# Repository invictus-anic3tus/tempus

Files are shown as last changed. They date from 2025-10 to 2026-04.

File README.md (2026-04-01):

<div align="center" width=100%>

  Tempus Title Image

  Tempus Title Image

  <p display="inline">

  

  </p>

  <h1></h1>

  <p>
    An open source, ESP32-based smartwatch!
  </p>
</div>

<sub>This work is licensed under a
[Creative Commons Attribution-NonCommercial 4.0 International License](https://creativecommons.org/licenses/by-nc/4.0/).
</sub>

## Table of Contents

- [About](#about)
- [Features](#features)
- [Specifications](#specifications)
- [Bill of Materials](#bill-of-materials)
- [Contributing](#contributing)

## About

My name is Anicetus, and I love hardware. The Anicept Tempus is my newest addition to my brand, and the first devboard PCB! There are others out there, and many are probably much better. But I felt it was high time I had one of my _own._ It might not beat the competition in price, features, quality, you name it; but there comes a certain satisfaction when you can wear (more like tout at this point) a semi-stylish, functional, and helpful item that you can point to and confidently say: "I created this from scratch."

And so, the Tempus is a small yet powerful ESP32 devboard PCB + case, equipped with all the features that a modern digital smartwatch would need. Fully able to track steps and gestures, voice text, make beeps and alerts with a buzzer, power a round touchscreen, and, of course, tell time, it's the ideal replacement for a multi-hundred-dollar smartwatch with the same features.

## Features

Speaking of features, this watch is equipped with the following:
- A precise, quick gyroscope/accelerometer for hand tracking
- WiFi and Bluetooth for connecting to your phone to receive texts and calls, as well as control music apps such as Spotify
- An RTC (Real Time Clock) chip capable of maintaining incredibly accurate time
- A vibration motor for alerts and ringtones
- A microphone for voice messaging or reminders. (Note: the watch doesn't have a speaker, so playing music, receiving calls, etc. must be done through headphones connected to a phone connected to the watch. Also, unfortunately the ESP32-S3 cannot be used as a microphone during calls, so for that you'll need to use your phone's built-in mic.)
- Two reprogrammable buttons, perfect for quick text replies, controlling music, or navigating to apps.
- A modern USB-C 2.0 charging and programming recepticle
- A 500mAh battery, to ensure minimal charging time
- A battery percentage monitor to ensure the watch never dies
- A 1.28" capacitive touch display

## How do I build this?

Good question! If you'd like to make the Tempus for yourself, there's a few things you should keep in mind:
1. You must have access to a 3D printer or be willing to pay for a printing service. TPU or another flexible filament is required for the watch band.
2. You must have access to soldering equipment and be skilled in soldering. This includes a hot air gun and solder paste.
3. This design necessitates a custom PCB. These can get expensive if you need to account for shipping or tariff costs.
4. This is _not_ a professional design! I'm a random guy from the internet who made a smartwatch design; if you want to make it for yourself, go ahead! But I am not responsible for any misuse or unintended happenings due to faulty design.
5. Commercial use is not allowed. You cannot make this watch to sell to anybody.

Alright! Now we can get into how to actually build it. First, download the gerber.zip file in the PCB_Production folder, go to your favorite PCB manufacturing service (JLCPCB and PCBWay are good) and upload it in their quote system. It should say four-layer PCB. Here are the settings to select:
(Make sure you know what you're doing before changing these! The color is self-explanatory, but colors other than green can be more expensive.)

JLCPCB settings

Then, order the DigiKey parts in [this cart](https://www.digikey.com/short/2mbbn5n0) and the screen from [BuyDisplay](https://www.buydisplay.com/1-28-inch-tft-lcd-display-240x240-round-circle-screen-for-smart-watch) or [eBay](https://www.ebay.com/itm/305668452899?var=604666595108).

Next, 3D print the files in the CAD folder. Detailed assembly instructions coming soon; for now, please reference the full CAD design!

Wiring

## Specifications

Nerd info incoming
- Main processor: ESP32-S3-Wroom-1
- Gyroscope/accelerometer: LSM6DSMTR
- RTC: DS3231M+
- Battery Charging: TPB4056B (A drop-in TP4056 replacement, available on DigiKey)
- Microphone: SPH0645LM4H-B
- Display: [1.28 inch 240x240 IPS TFT LCD Round Circle Capacitive Touch Screen](https://www.buydisplay.com/1-28-inch-tft-lcd-display-240x240-round-circle-screen-for-smart-watch)
- Main 3v3 Buck-Boost Converter: TPS63031DSKR

Tempus Schematic-1

PCB

## Bill of Materials

| Item |  Price  | Link | Shipping |
|---|---|---|---|
| PCB | $2 | <https://jlcpcb.com> | $3.18 |
| DigiKey Parts* | $67.34  | <https://www.digikey.com/short/2mbbn5n0> | $6.99 |
| Screen | $8.85 | <https://www.buydisplay.com/1-28-inch-tft-lcd-display-240x240-round-circle-screen-for-smart-watch> | $8.12 |
| Total | $78.19  | | $18.29 |

*Including subjective tariffs, taxes, etc. Also includes battery and solder paste.

An online DigiKey cart is available at <https://www.digikey.com/short/2mbbn5n0>.

### Grand Total: ±$96.48

(Recommended planned price: $100)

## Contributing

<sub>aha somebody wishes to help me i see</sub>

If you'd like to request changes, suggest additions, or forcefully make me edit things, feel free to contact me via email (`me at anicetus dot dev`, preferred) or Discord (anic3tus).

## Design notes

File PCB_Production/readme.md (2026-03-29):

PCB Source files (schematic, board layout, etc.)

As this watch was designed to be hand-soldered, the assembly files have not been tested. The BOM, however, does contain LCSC part numbers for every component on the PCB. The gerbers are tested and work correctly.

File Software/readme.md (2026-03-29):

I'm very bad at coding, but I used Claude (💀) as a tool to make this code. It's for Arduino IDE, so upload the Anicept_Tempus file, and use the .ino file for downloading the code onto the board. It should work, I'm pretty sure?

Ahhhh i can't code ;-;

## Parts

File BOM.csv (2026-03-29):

Item | Price | Link | Shipping
PCB | $2 | https://jlcpcb.com | $3.18
DigiKey Parts* | $57.74 | https://www.digikey.com/short/2mbbn5n0 | $6.99
Screen | $8.85 | https://www.buydisplay.com/1-28-inch-tft-lcd-display-240x240-round-circle-screen-for-smart-watch | $8.12
Total | $68.59 |  | $18.29
*See the readme for more information

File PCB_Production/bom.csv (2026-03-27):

Designator | Footprint | Quantity | Value | LCSC Part #
C1, C13, C21, C5 | 0805 | 4 | 1µF | C28323
C10, C11, C14, C15, C7, C9 | 0805 | 6 | 10µF | C15850
C12, C2, C4, C6, C8 | 0805 | 5 | 0.1µF | C1711
C22 | 0805 | 1 | 220pF | C472838
C3 | 0805 | 1 | 22uF | C602037
D1,D7 | 0805 | 2 | LED | C25170728
D2,D3 | D_SOD-123 | 2 | D_Schottky | C190475
D6 | 0805 | 1 | LED | C19171391
J1 | USB_C_Receptacle_G-Switch_GT-USB-7010ASV | 1 | USB_C_Receptacle_USB2.0_16P | C2988369
J2 | Amphenol_F32Q-1A7x1-11015_1x15-1MP_P0.5mm_Horizontal | 1 | Conn_01x15 | C3168240
J3 | JST_ZH_B2B-ZR_1x02_P1.50mm_Vertical | 1 | Conn_01x02 | C163033
J4, J5 | JST_SH_BM05B-SRSS-TB_1x05-1MP_P1.00mm_Vertical | 2 | JST_SH_BM05B-SRSS-TB_1x05-1MP_P1.00mm_Vertical | C160391
L1 | L_Coilcraft_LPS3010 | 1 | 1.5µH | C17382749
MK1 | Knowles_SPH0645LM4H-6_3.5x2.65mm | 1 | SPH0645LM4H | C19190864
Q1 | SOT-23 | 1 | NPN | C81464
Q2 | SOT-23 | 1 | 2N7002 | C916396
Q3 | SOT-23 | 1 | IRLML6401 | C382329
R1, R13, R20, R23, R4, R7, R8, R9 | 0805 | 8 | 10K | C84376
R10, R19 | 0805 | 2 | 100K | C149504
R11 | 0805 | 1 | 1K | C17513
R12 | 0805 | 1 | 8.2 | C2930335
R14, R15 | 0805 | 2 | 180 | C2933344
R16 | 0805 | 1 | 0.4 | C3000778
R17 | 0805 | 1 | 2.4K | C865376
R18 | 0805 | 1 | 33K | C17633
R2, R24 | 0805 | 2 | 68 | C17802
R3 | 0805 | 1 | 0 | C17477
R5, R6 | 0805 | 2 | 5.1K | C27834
SW1, SW2 | SW-SMD_L3.9-W3.0-P4.45 | 2 | SW_Push | C720477
SW3, SW4 | Button_Switch_SMD:SW_EVQ-P7C01P | 2 | SW_Push | C388883
U1 | ESP32-S3-WROOM-1 | 1 | ESP32-S3-WROOM-1 | C2913202
U2 | LGA-14_3x2.5mm_P0.5mm_LayoutBorder3x4y | 1 | LSM6DSM | C94048
U3 | SOT-23-6 | 1 | USBLC6-2SC6 | C7519
U4 | SOIC-16W_7.5x10.3mm_P1.27mm | 1 | DS3231M | C37663
U5 | SOT-89-3 | 1 | MCP1700x-300xxMB | C57883
U6 | SOIC-8-1EP_3.9x4.9mm_P1.27mm_EP2.41x3.3mm_ThermalVias | 1 | TP4056-42-ESOP8 | C16581
U7 | WSON-10-1EP_2.5x2.5mm_P0.5mm_EP1.2x2mm | 1 | TPS63031DSK | C15516

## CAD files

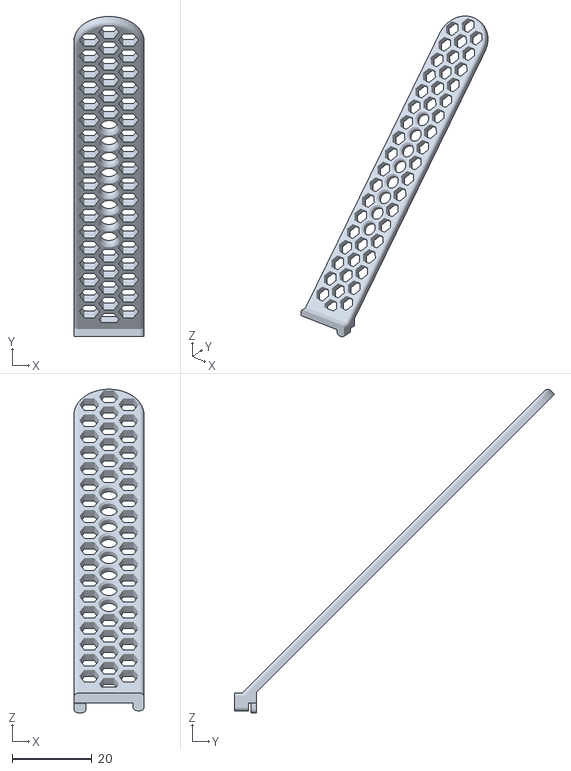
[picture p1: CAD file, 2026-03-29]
CAD/Bottom Strap.stl
17.6 x 80.0 x 80.9

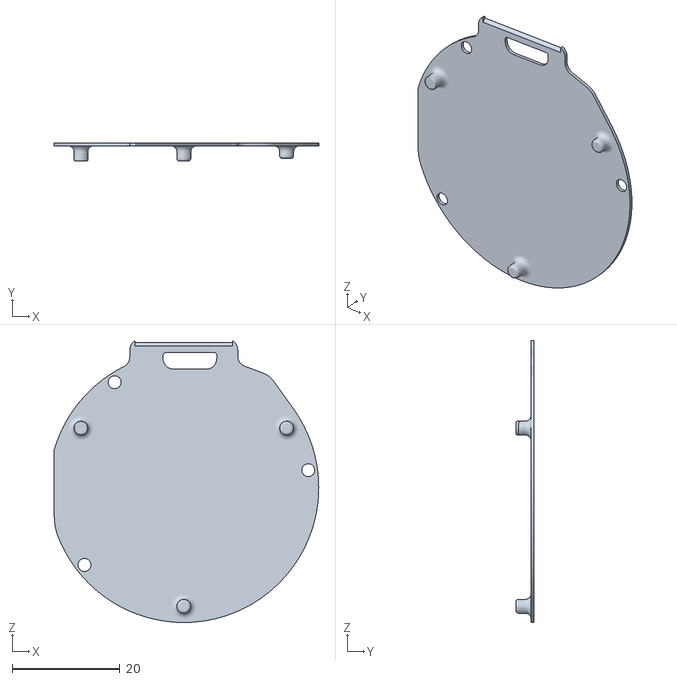
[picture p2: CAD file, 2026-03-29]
CAD/Back Cover.stl
49.0 x 3.40 x 52.2

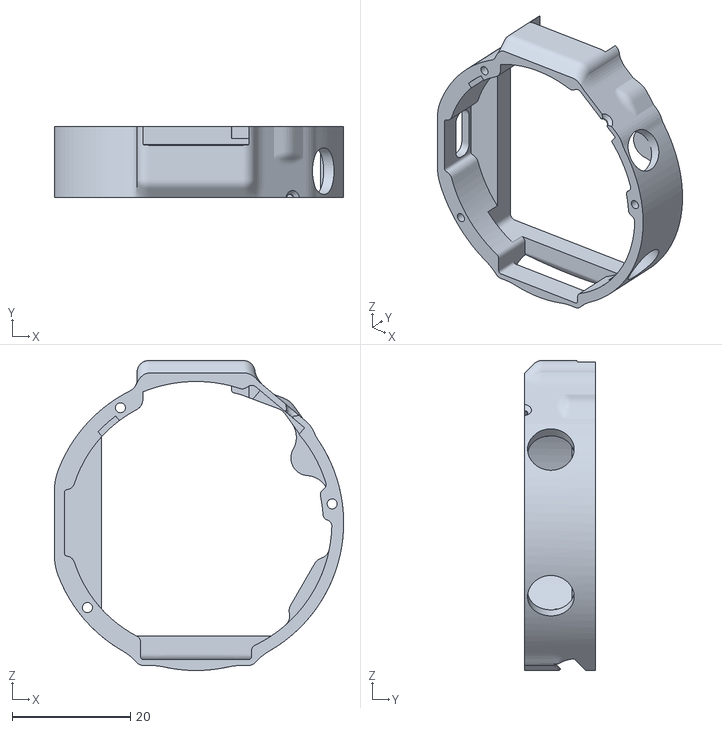
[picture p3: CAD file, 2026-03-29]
CAD/Bottom Piece.stl
49.0 x 12.0 x 52.5

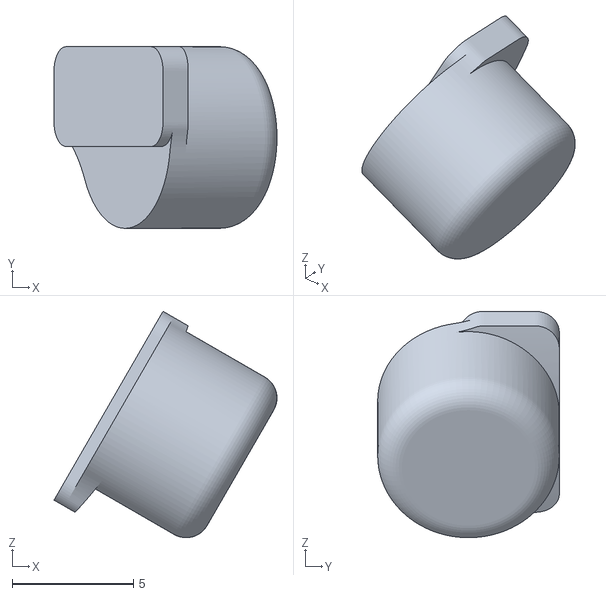
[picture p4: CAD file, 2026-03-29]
CAD/Bottom Button.stl
9.21 x 7.50 x 9.35

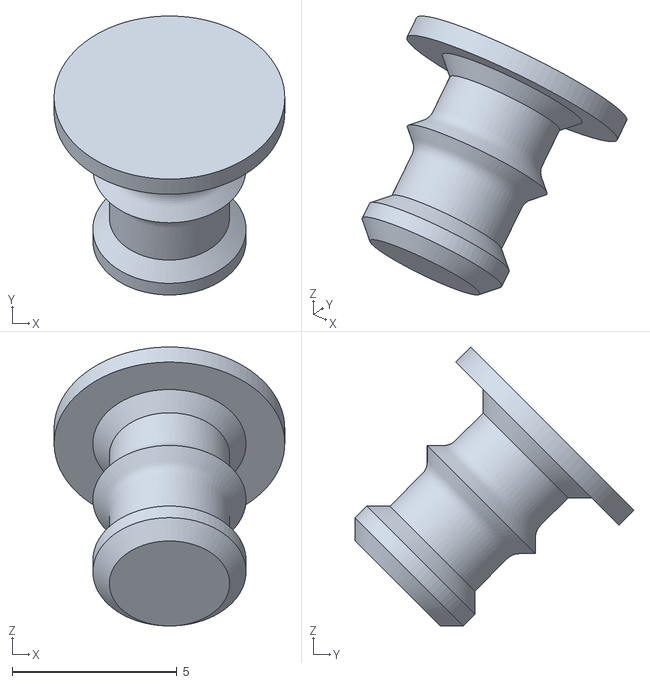
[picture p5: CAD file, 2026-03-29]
CAD/Strap Lock.stl
7.00 x 8.47 x 8.47

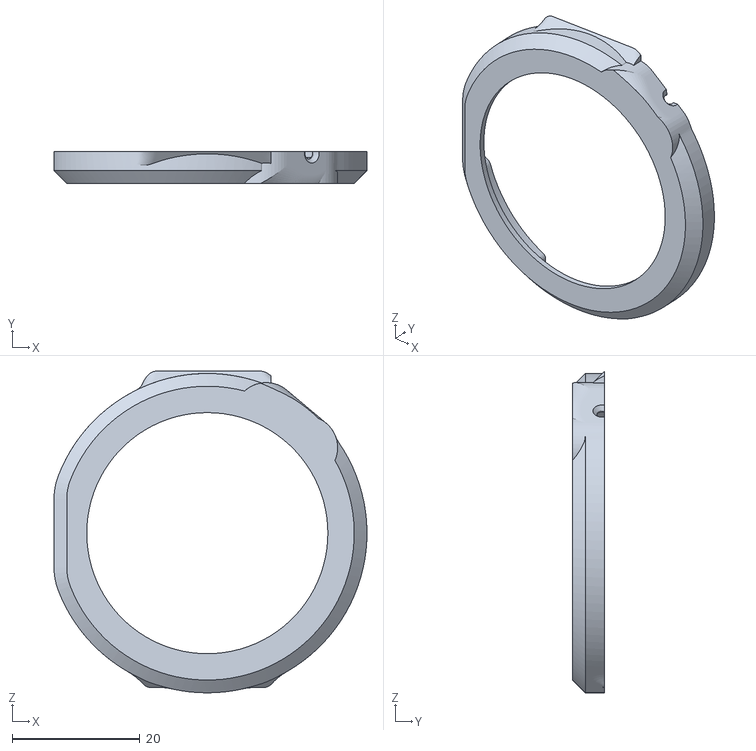
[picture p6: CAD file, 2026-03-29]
CAD/Top Piece.stl
49.0 x 5.00 x 50.4

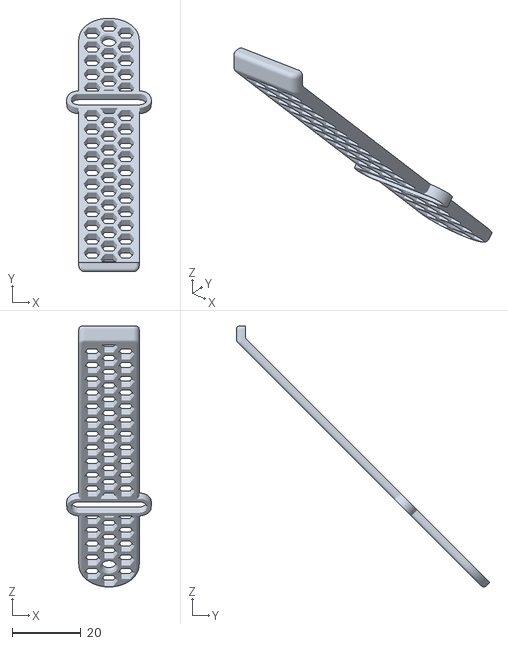
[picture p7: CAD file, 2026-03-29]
CAD/Top Strap.stl
24.6 x 73.7 x 75.9

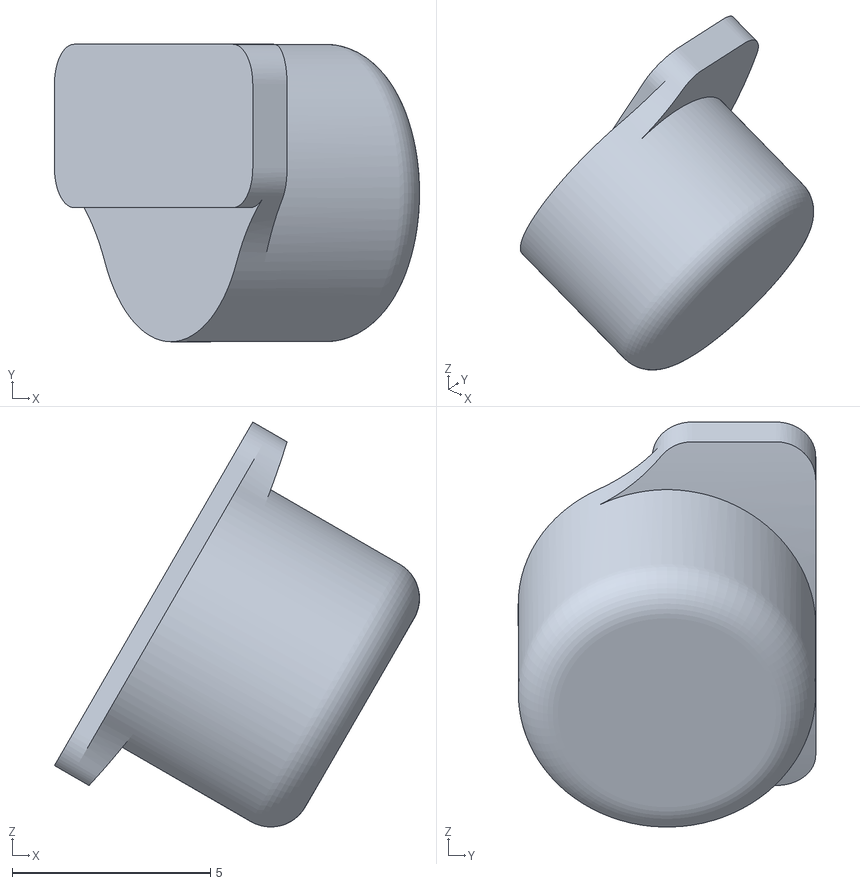
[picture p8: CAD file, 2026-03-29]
CAD/Top Button.stl
9.21 x 7.50 x 10.2

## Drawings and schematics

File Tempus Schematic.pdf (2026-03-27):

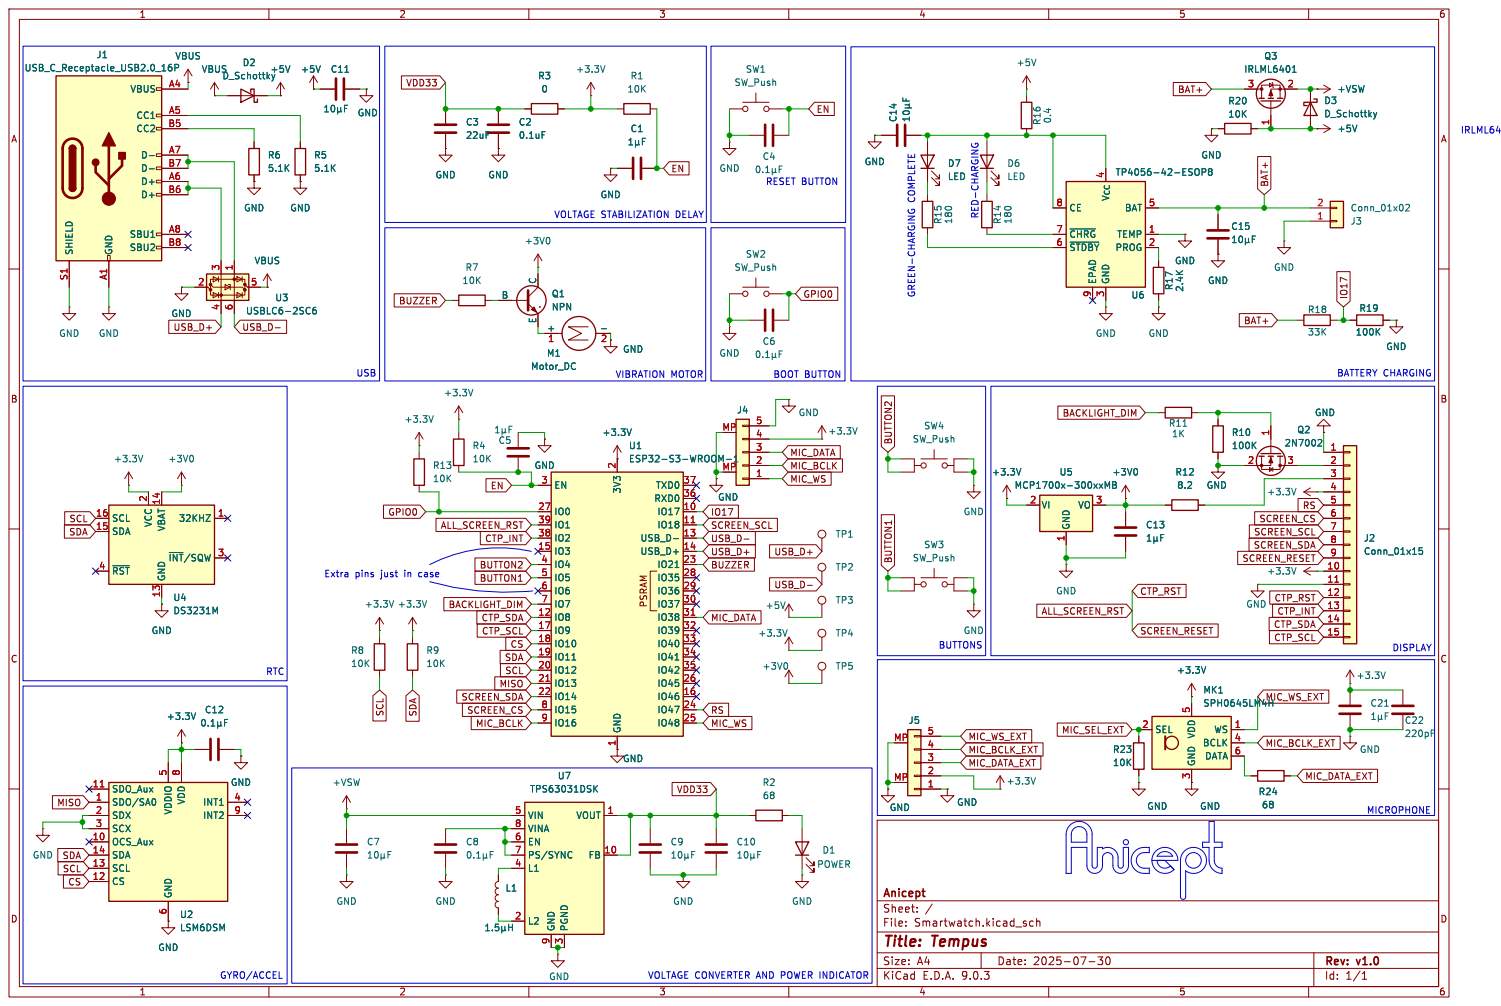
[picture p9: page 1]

3 BAT 5 TEMP 1 PROG 2 R17 2.4K GND Q3

3 BAT 5 TEMP 1 PROG 2 U6 TP4056-42-ESOP8 GND

3 WS 1 BCLK 4 DATA 6 MK1 SPH0645LM4H MISO GND

5 MP MP GND GND

3 WS 1 BCLK 4 DATA 6 GND

File: Smartwatch.kicad_sch Sheet: / Anicept +VSW

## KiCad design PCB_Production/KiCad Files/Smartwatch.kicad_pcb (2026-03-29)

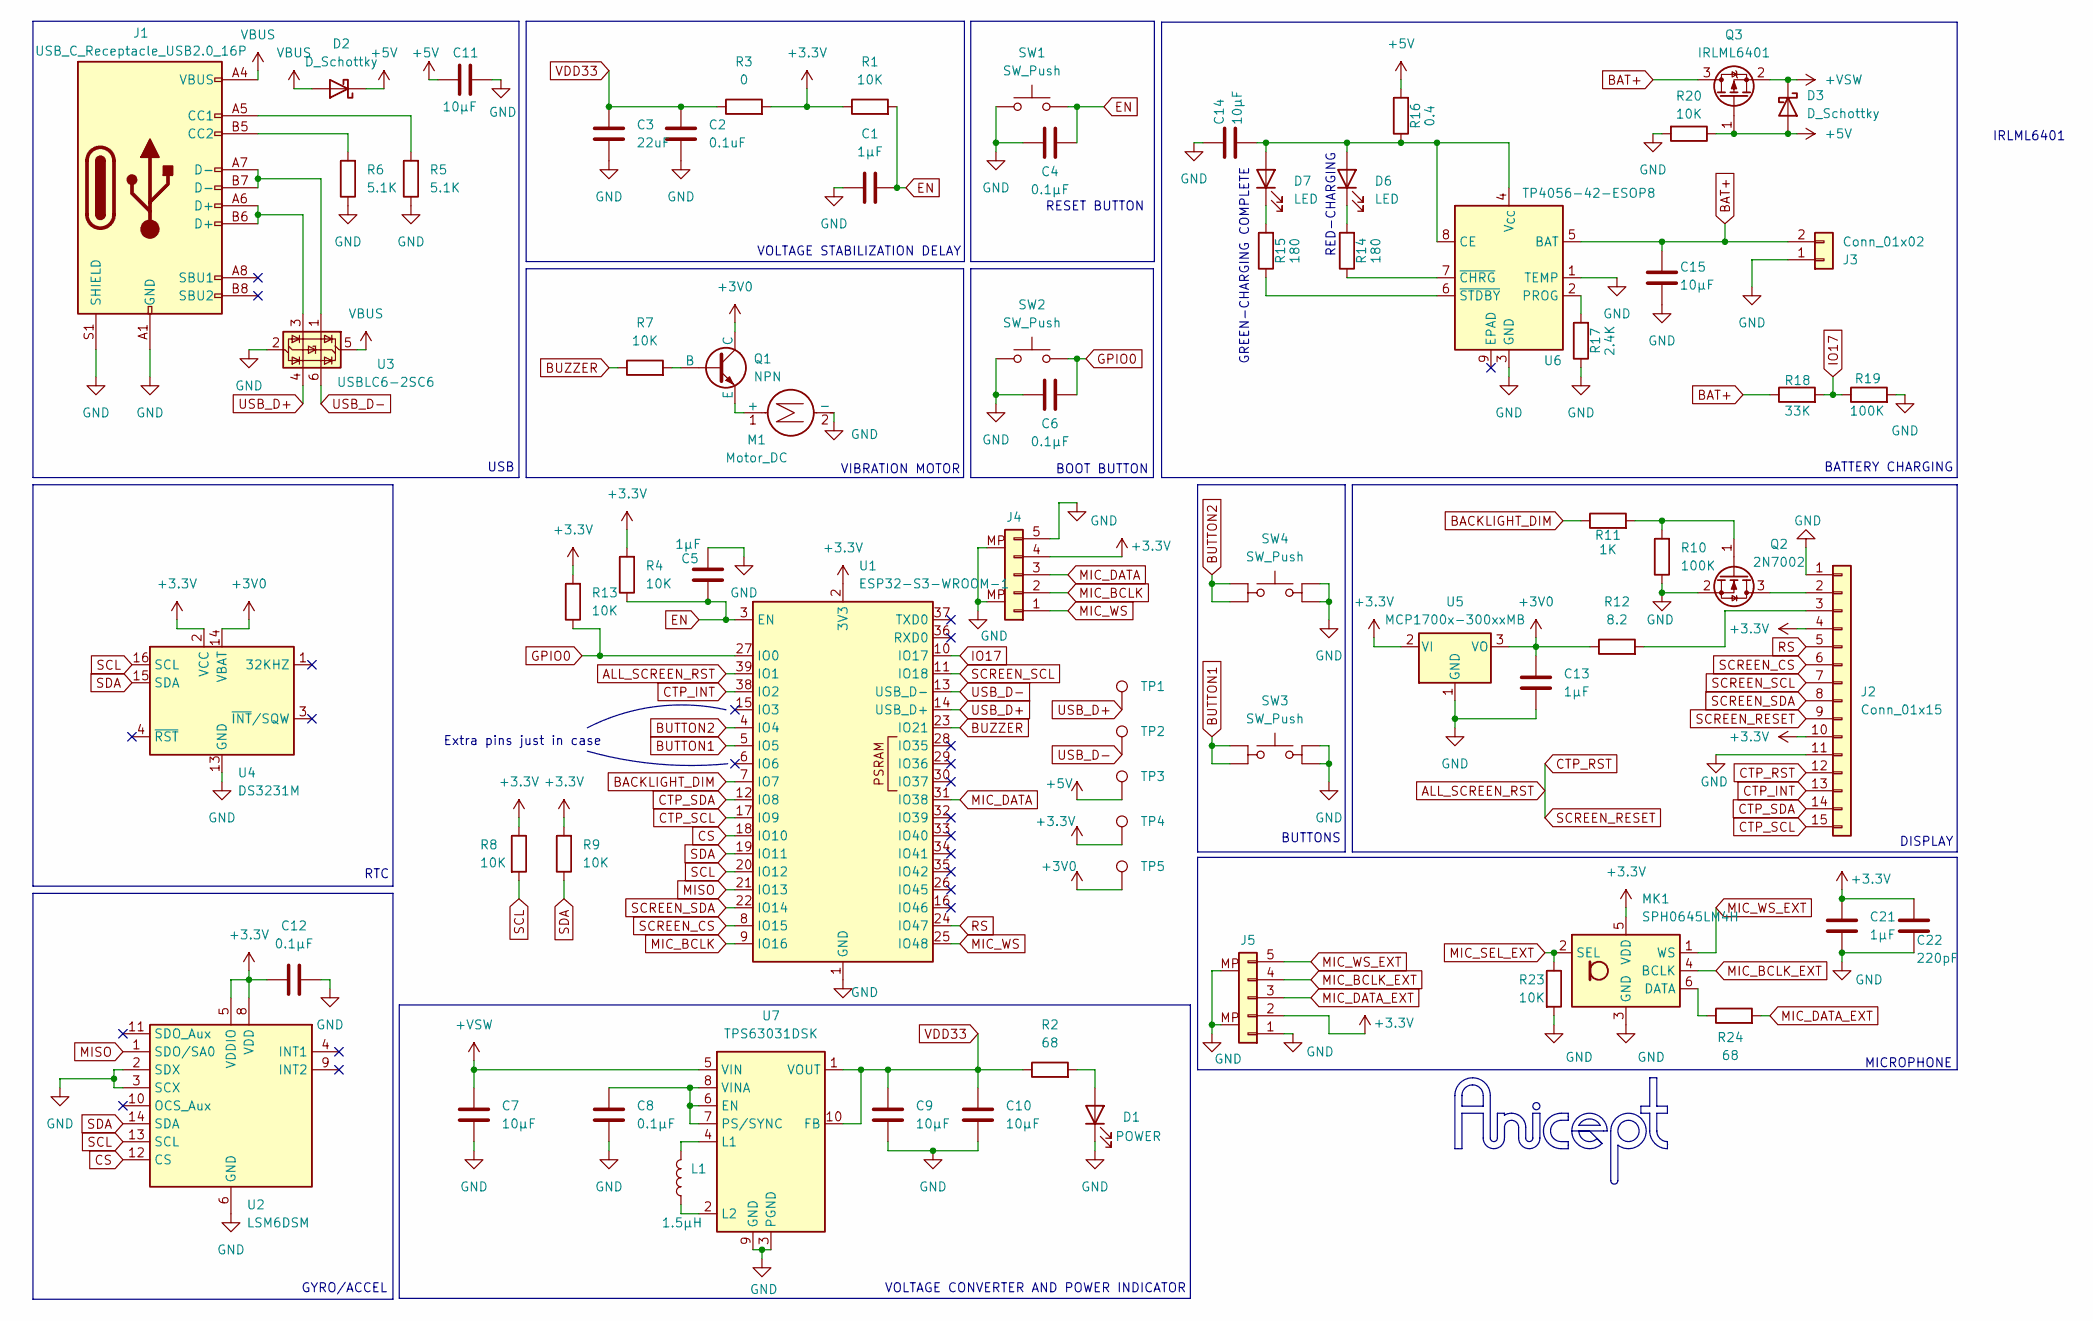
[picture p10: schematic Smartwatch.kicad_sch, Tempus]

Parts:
C1, C5, C13, C21: 1µF; C_0805_2012Metric
C2: 0.1uF; C_0805_2012Metric
C3: 22uF; C_0805_2012Metric
C4, C6, C8, C12: 0.1µF; C_0805_2012Metric
C7, C9, C10, C11, C14, C15: 10µF; C_0805_2012Metric
C22: 220pF; C_0805_2012Metric
D1: POWER; LED_0805_2012Metric
D2, D3: D_Schottky; D_SOD-123
D6, D7: LED; LED_0805_2012Metric
J1: USB_C_Receptacle_USB2.0_16P; USB_C_Receptacle_G-Switch_GT-USB-7010ASV
J2: Conn_01x15; Amphenol_F32Q-1A7x1-11015_1x15-1MP_P0.5mm_Horizontal
J3: Conn_01x02; JST_ZH_B2B-ZR_1x02_P1.50mm_Vertical
J4, J5: JST_SH_BM05B-SRSS-TB_1x05-1MP_P1.00mm_Vertical
L1: 1.5µH; IND_LQH3NPN1R5MJRL
M1: Motor_DC; TestPoint_Pad_1.5x1.5mm
MK1: SPH0645LM4H; Knowles_SPH0645LM4H-6_3.5x2.65mm
Q1: NPN; SOT-23
Q2: 2N7002; SOT-23
Q3: IRLML6401; SOT-23
R1, R4, R7, R8, R9, R13, R20, R23: 10K; R_0805_2012Metric
R2, R24: 68; R_0805_2012Metric
R3: 0; R_0805_2012Metric
R5, R6: 5.1K; R_0805_2012Metric
R10, R19: 100K; R_0805_2012Metric
R11: 1K; R_0805_2012Metric
R12: 8.2; R_0805_2012Metric
R14, R15: 180; R_0805_2012Metric
R16: 0.4; R_0805_2012Metric
R17: 2.4K; R_0805_2012Metric
R18: 33K; R_0805_2012Metric
SW1, SW2: SW_Push; SW-SMD_L3.9-W3.0-P4.45
SW3, SW4: SW_Push; SW_EVQ-P7C01P
TP1, TP2, TP3, TP4, TP5: TestPoint_Pad_1.0x1.0mm
U1: ESP32-S3-WROOM-1
U2: LSM6DSM; LGA-14_3x2.5mm_P0.5mm_LayoutBorder3x4y
U3: USBLC6-2SC6; SOT-23-6_Handsoldering
U4: DS3231M; SOIC-16W_7.5x10.3mm_P1.27mm
U5: MCP1700x-300xxMB; SOT-89-3
U6: TP4056-42-ESOP8; SOIC-8-1EP_3.9x4.9mm_P1.27mm_EP2.41x3.3mm_ThermalVias
U7: TPS63031DSK; WSON-10-1EP_2.5x2.5mm_P0.5mm_EP1.2x2mm_ThermalVias

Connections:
+3.3V: C12.2, C21.2, C22.2, J2.4, J2.10, J4.4, J5.2, MK1.5 (VDD), R1.1, R3.2, R4.2, R8.1, R9.2, R13.2, TP4.1, U1.2 (3V3), U2.5 (VDDIO), U2.8 (VDD), U4.2 (VCC), U5.2 (VI)
+3V0: C13.2, Q1.1 (C), R12.1, TP5.1, U4.14 (VBAT), U5.3 (VO)
+5V: C11.2, D2.1 (K), D3.2 (A), Q3.1 (G), R16.2, R20.1, TP3.1
+VSW: C7.2, D3.1 (K), Q3.2 (S), U7.5 (VIN)
ALL_SCREEN_RST: J2.9, J2.12, U1.39 (IO1)
BACKLIGHT_DIM: R11.1, U1.7 (IO7)
BAT+: C15.2, J3.2, Q3.3 (D), R18.1, U6.5 (BAT)
BUTTON1: SW3.1_1, SW3.1_2, U1.5 (IO5)
BUTTON2: SW4.1_1, SW4.1_2, U1.4 (IO4)
BUZZER: R7.1, U1.23 (IO21)
CS: U1.18 (IO10), U2.12 (CS)
CTP_INT: J2.13, U1.38 (IO2)
CTP_SCL: J2.15, U1.17 (IO9)
CTP_SDA: J2.14, U1.12 (IO8)
EN: C1.2, C4.1, C5.1, R1.2, R4.1, SW1.2, U1.3 (EN)
GND: C1.1, C2.1, C3.1, C4.2, C5.2, C6.2, C7.1, C8.1, C9.1, C10.1, C11.1, C12.1, C13.1, C14.2, C15.1, C21.1, C22.1, D1.1 (K), J1.A1 (GND), J1.A12 (GND), J1.B1 (GND), J1.B12 (GND), J1.S1 (SHIELD), J2.1, J2.11, J3.1, J4.5, J4.MP, J5.1, J5.MP, M1.2 (-), MK1.3 (GND), Q2.2 (S), R5.1, R6.1, R10.1, R17.1, R19.2, R20.2, R23.2, SW1.1, SW2.1, SW3.2_1, SW3.2_2, SW4.2_1, SW4.2_2, U1.1 (GND), U1.40 (GND), U1.41 (GND), U2.2 (SDX), U2.3 (SCX), U2.6 (GND), U2.7 (GND), U3.2 (GND), U4.5 (GND), U4.6 (GND), U4.7 (GND), U4.8 (GND), U4.9 (GND), U4.10 (GND), U4.11 (GND), U4.12 (GND), U4.13 (GND), U5.1 (GND), U6.1 (TEMP), U6.3 (GND), U7.3 (PGND), U7.9 (GND), U7.11 (PGND)
GPIO0: C6.1, R13.1, SW2.2, U1.27 (IO0)
IO17: R18.2, R19.1, U1.10 (IO17)
MIC_BCLK: J4.2, U1.9 (IO16)
MIC_BCLK_EXT: J5.4, MK1.4 (BCLK)
MIC_DATA: J4.3, U1.31 (IO38)
MIC_DATA_EXT: J5.3, R24.2
MIC_SEL_EXT: MK1.2 (SEL), R23.1
MIC_WS: J4.1, U1.25 (IO48)
MIC_WS_EXT: J5.5, MK1.1 (WS)
MISO: U1.21 (IO13), U2.1 (SDO/SA0)
unnamed: D1.2 (A), R2.2
unnamed: C14.1, D6.2 (A), D7.2 (A), R16.1, U6.4 (V_{CC}), U6.8 (CE)
unnamed: D6.1 (K), R14.2
unnamed: D7.1 (K), R15.2
unnamed: J1.A5 (CC1), R5.2
unnamed: J1.B5 (CC2), R6.2
unnamed: J1.A6 (D+), J1.B6 (D+), U3.3 (I/O2)
unnamed: J1.A7 (D-), J1.B7 (D-), U3.1 (I/O1)
unnamed: J2.2, Q2.3 (D)
unnamed: J2.3, R12.2
unnamed: M1.1 (+), Q1.3 (E)
unnamed: MK1.6 (DATA), R24.1
unnamed: Q1.2 (B), R7.2
unnamed: Q2.1 (G), R10.2, R11.2
unnamed: R17.2, U6.2 (PROG)
unnamed: R14.1, U6.7 (~CHRG)
unnamed: R15.1, U6.6 (~STDBY)
unnamed: C8.2, U7.6 (EN), U7.7 (PS/SYNC), U7.8 (VINA)
unnamed: L1.2, U7.4 (L1)
unnamed: L1.1, U7.2 (L2)
RS: J2.5, U1.24 (IO47)
SCL: R8.2, U1.20 (IO12), U2.13 (SCL), U4.16 (SCL)
SCREEN_CS: J2.6, U1.8 (IO15)
SCREEN_SCL: J2.7, U1.11 (IO18)
SCREEN_SDA: J2.8, U1.22 (IO14)
SDA: R9.1, U1.19 (IO11), U2.14 (SDA), U4.15 (SDA)
USB_D+: TP1.1, U1.14 (USB_D+), U3.4 (I/O2)
USB_D-: TP2.1, U1.13 (USB_D-), U3.6 (I/O1)
VBUS: D2.2 (A), J1.A4 (VBUS), J1.A9 (VBUS), J1.B4 (VBUS), J1.B9 (VBUS), U3.5 (VBUS)
VDD33: C2.2, C3.2, C9.2, C10.2, R2.1, R3.1, U7.1 (VOUT), U7.10 (FB)

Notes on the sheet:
MICROPHONE
VIBRATION MOTOR
USB
VOLTAGE STABILIZATION DELAY
BUTTONS
BATTERY CHARGING
RTC
Extra pins just in case
BOOT BUTTON
RESET BUTTON
IRLML6401
GYRO/ACCEL
VOLTAGE CONVERTER AND POWER INDICATOR
GREEN-CHARGING COMPLETE
DISPLAY
RED-CHARGING

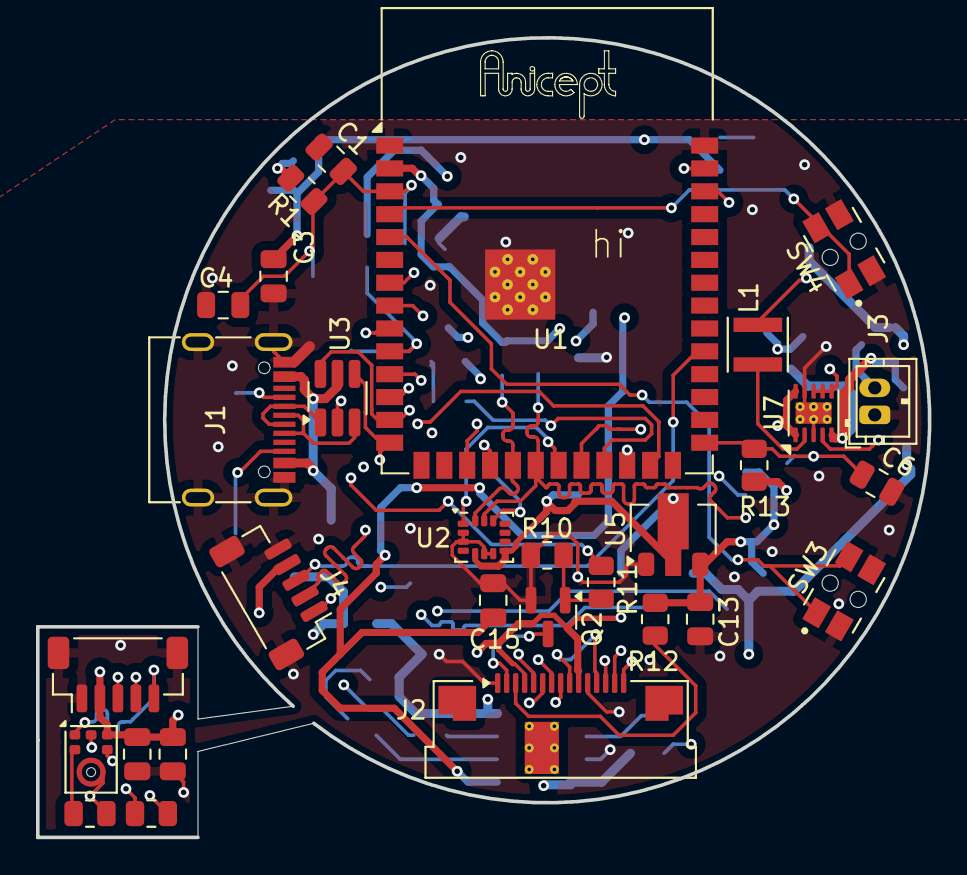
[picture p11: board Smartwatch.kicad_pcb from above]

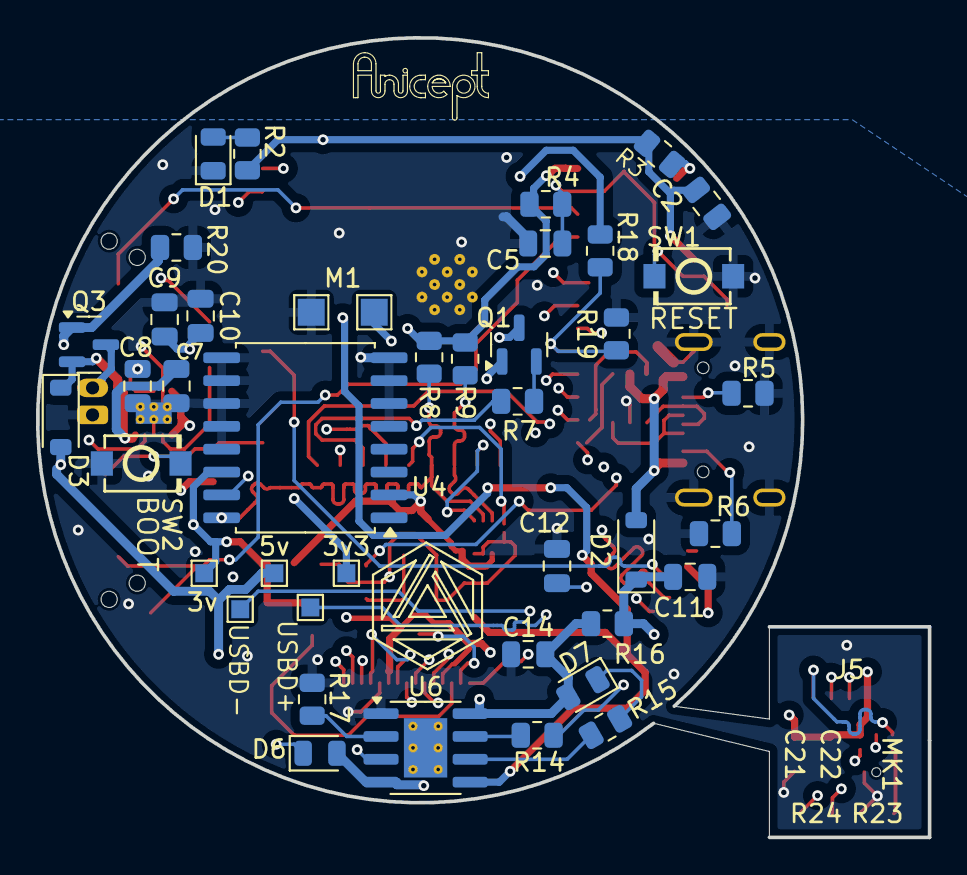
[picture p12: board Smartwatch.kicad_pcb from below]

Board: 4 copper layers, 49.5 x 44.4 mm, 71 parts (41 on the bottom side), 56 nets.

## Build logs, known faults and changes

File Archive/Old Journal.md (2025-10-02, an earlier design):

---
title: "Tempus"
author: "Anicetus"
description: "A flashy, powerful ESP32-based smartwatch"
created_at: "2025-07-21"
---

## total time: 34 hrs

# firstly
i want to thank everybody at hack club who's making this possible. if you don't know, hack club is a 100% 501(c)(3) nonprofit run by zach latta + friends made for coders and electronics peoples 18 and under. this project is made possible through their highway to undercity program, where teens are empowered to build their dreams with up to $350 in funding!

so a big thank you out to acon, alex ren, cyao, ducc, bunnyguy, phthallo, paolo, kareem, rhys, kl, ian, tongyu, manitej, cinders, and m0hid!!

## i'm anicetus
if you're reading this on hack club, you may very well already know me. but if you dont, here's a bit of info:  
1. I live in the usa  
2. i'm ok at coding  
3. but i think im pretty good at electronics and stuff!  
4. i've designed a custom drone  
5. and a custom 3d printer  

so yeah i've got a bit to put on my resume! but anyways let's get down to business.

## log

### day one - july 21st

today i started out by googling some schematics for esp32 devkits. I don't plan to copy them line-for-line, but for necessary stuff like the power converters and whatnot I'll look at them, figure out why each component is there, then and only then add it to my own schematic. After learning what some of the parts do, I may even omit them, namely the second USB port on the ESP32 S3 DevkitC 1. I got a little done, but mostly just reviewing and researching what stuff in the schematic did.

#### 2 hrs

### day two - july 22nd

today I worked mostly on other projects, but I got a tiny bit of time in copying more of the schematic. I added the voltage converter thingy that turns 5v into 3.3v, and this was the first time I really had to improvise. I couldn't find the component the original devkit uses in stock anywhere, so I took the liberty of looking for one myself. I found the LM1117, which is a fixed-voltage outputter, meaning each one can only output a certain voltage instead of being adjustable. This is good since I don't need extra resistors or anything to control it.

schem

#### 0.5 hrs

### day three - july 23rd

DEADLINE APPROADCHING AAAAAAAAAAAAAAAAAAAAAAAAAAAAAAAAAAAAAAAAAA

today i copied more of the schematic. I'm using a THT USB-C 2.0 instead of a microusb to make it nicer, but it came with a _lot_ of research. Like, a _**lot**_. I got it done tho!

schem

#### 2.5 hrs

### days four through six - july 24 - 26

these days I just worked on copying the schematic more. I added an RTC clock, a gyroscope, and other miscellaneous items, and I started work on the display. It's going to take a ton of GPIOs, and I hope I'll have enough without having to use an IO expander!

#### 7 hrs total

### day seven - july 27

uh oh. today i realized that i built the entire display part of the schematic around a display without a touchscreen! i had to delete it, do more research to find an actual touchscreen, and replace it. All in all it wasn't too difficult, though. I found the new display on <https://buydisplay.com>, which seems to be a fairly legit Chinese display seller. I did a bunch of PCB work too!

#### 2 hrs

### day eight - july 28

ok welp yesterday was kinda useless. Turns out when you make a circle in Kicad for the board outline, you're defining the radius, not the diameter like I'm used to in f360. Basically i made the watch 4x as big as it should be and the entire pcb has to be scrapped. Now normally this would be devastating, especially with the july 31st highway deadline. However, I've decided to submit it for [Grounded](https://grounded.hackclub.com) instead! The grounded deadline is _August_ 31st, meaning I have an entire extra month to make this thing. I also decided that instead of a round display like I found yesterday, I'm gonna try to find a square display with rounded corners, since I think they look better. I deleted everything in the PCB, which, by the way, I had just completed, and reimported from the schematic.

I have a few minor changes in mind, such as removing the RTC battery and just using the one lipo battery, and I was informed that I need a pullup resistor on GPIO0 and a schottky diode to prevent current backflow from the battery to the USB port. I also have to connect both D+ and D-'s of the usb receptacle, and I might remove the 3.3V -> 3V voltage converter for the display backlight. We'll see!

#### 3 hrs

### days nine and ten - august 8 and 9

i added the changes i said on day eight, and did a few more. I added four programmable buttons and some other stuff, and nearly finished routing the PCB! (again).

But an image is worth a thousand words, so here's four images: (worth 4000 words?)









#### 4.5 hrs total

### day eleven - september 1

phew! that was a big gap! i've been doing a lot of work on [my drone](https://github.com/invictus-anic3tus/v4) and haven't had much time for this. But today I added a silkscreen and finished routing! pics tmrw probably :3

#### 3 hrs

### day twelve - september 17

today i did a ton of stuff trying to figure out adding a speaker to the watch in place of the buzzer!!!!!!!! had a bit of a standstill trying to figure out how to implement a digital pot but i think i'll get it eventually

#### 1.5 hrs

### day thirteen - september 18

welp just realized i cant do the speaker cuz im out of gpios and there's no room for an io expander 😭
but thats ok, i might find a way to connect it to bluetooth headphones? anyway i did add a microphone though! That was very informative, but i'm not sure how well its gonna work cuz it'll be all but covered up by the case. ig i'll figure it out. i'm proud of how much work i did today--i also added two more layers and rerouted the spi and i2c lines to help de-clutter stuff.







#### 3 hrs

### day fourteen - september 19

today i finalized positioning the mic and DRC + silkscreen fixing. I reorganized the schematic a bunch so now it's super pretty :3



#### 2 hrs

### day fifteen - september 20

today i made a good lookin readme and got my production files and did a bunch trying to get my BOM from Kicad but it's sooooooo tedious holy cow

#### 3 hrs

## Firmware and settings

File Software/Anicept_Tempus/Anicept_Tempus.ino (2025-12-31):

#include <TFT_eSPI.h>
#include <RTClib.h>
#include <Wire.h>
#include <LSM6DSOXSensor.h>
#include <Preferences.h>
#include <BLEDevice.h>
#include <BLEServer.h>
#include <BLEUtils.h>
#include <BLE2902.h>

#include "config.h"
#include "globals.h"
#include "icons.h"
#include "ble_functions.h"
#include "sensor_functions.h"
#include "display_functions.h"
#include "app_clock.h"
#include "app_messages.h"
#include "app_phone.h"
#include "app_music.h"
#include "app_health.h"
#include "app_camera.h"
#include "app_settings.h"
#include "app_clocktools.h"
#include "app_compass.h"

void setup() {
  Serial.begin(115200);
  Serial.println("ESP32 Smartwatch Starting...");
  
  // Initialize pins
  pinMode(BUTTON_1, INPUT_PULLUP);
  pinMode(BUTTON_2, INPUT_PULLUP);
  pinMode(BUZZER_PIN, OUTPUT);
  pinMode(BATTERY_PIN, INPUT);
  
  // Initialize I2C
  Wire.begin(I2C_SDA, I2C_SCL);
  
  // Initialize display
  tft.init();
  tft.setRotation(0);
  tft.fillScreen(TFT_BLACK);
  
  // Initialize RTC
  if (!rtc.begin()) {
    Serial.println("RTC not found!");
  } else {
    Serial.println("RTC initialized");
  }
  
  // Initialize IMU
  if (lsm6dsox.begin() != LSM6DSOX_OK) {
    Serial.println("IMU not found!");
  } else {
    lsm6dsox.Enable_X();
    lsm6dsox.Enable_G();
    Serial.println("IMU initialized");
  }
  
  // Load settings from flash
  loadSettings();
  
  // Initialize BLE
  initBLE();
  
  // Show boot screen
  showBootScreen();
  delay(2000);
  
  // Go to clock
  currentApp = APP_CLOCK;
  currentScreen = SCREEN_MAIN_CLOCK;
  screenActive = true;
  lastActivity = millis();
  
  Serial.println("Setup complete!");
}

void loop() {
  // Check buttons
  checkButtons();
  
  // Update sensors
  updateSensors();
  
  // Check gestures
  if (settings.gestureControl) {
    checkGestures();
  }
  
  // Handle touch input (if touch screen)
  // checkTouch();
  
  // Update current app display
  updateCurrentApp();
  
  // Screen timeout
  if (screenActive && millis() - lastActivity > SCREEN_TIMEOUT) {
    screenActive = false;
    tft.fillScreen(TFT_BLACK);
    Serial.println("Screen off");
  }
  
  delay(50);
}

void checkButtons() {
  static bool btn1Last = HIGH;
  static bool btn2Last = HIGH;
  static unsigned long btn1PressTime = 0;
  static unsigned long btn2PressTime = 0;
  
  bool btn1 = digitalRead(BUTTON_1);
  bool btn2 = digitalRead(BUTTON_2);
  
  // Button 1 - Short press
  if (btn1 == LOW && btn1Last == HIGH) {
    btn1PressTime = millis();
    delay(DEBOUNCE_DELAY);
  }
  
  if (btn1 == HIGH && btn1Last == LOW) {
    unsigned long pressDuration = millis() - btn1PressTime;
    lastActivity = millis();
    
    if (!screenActive) {
      screenActive = true;
      Serial.println("Screen on - Button 1");
    } else if (pressDuration < LONG_PRESS_TIME) {
      // Short press - go to app or go back
      if (currentScreen == SCREEN_MAIN_CLOCK) {
        currentApp = (AppID)settings.button1App;
        currentScreen = SCREEN_APP;
        Serial.print("Button 1 -> App: ");
        Serial.println(currentApp);
      } else {
        currentScreen = SCREEN_MAIN_CLOCK;
        currentApp = APP_CLOCK;
        Serial.println("Back to clock");
      }
    } else {
      // Long press - go to home/app launcher
      currentScreen = SCREEN_APP_LAUNCHER;
      Serial.println("Long press - App launcher");
    }
  }
  
  // Button 2 - Short press
  if (btn2 == LOW && btn2Last == HIGH) {
    btn2PressTime = millis();
    delay(DEBOUNCE_DELAY);
  }
  
  if (btn2 == HIGH && btn2Last == LOW) {
    unsigned long pressDuration = millis() - btn2PressTime;
    lastActivity = millis();
    
    if (!screenActive) {
      screenActive = true;
      Serial.println("Screen on - Button 2");
    } else if (pressDuration < LONG_PRESS_TIME) {
      if (currentScreen == SCREEN_MAIN_CLOCK) {
        currentApp = (AppID)settings.button2App;
        currentScreen = SCREEN_APP;
        Serial.print("Button 2 -> App: ");
        Serial.println(currentApp);
      } else {
        currentScreen = SCREEN_MAIN_CLOCK;
        currentApp = APP_CLOCK;
        Serial.println("Back to clock");
      }
    }
  }
  
  btn1Last = btn1;
  btn2Last = btn2;
}

void updateCurrentApp() {
  if (!screenActive) return;
  
  Theme t = themes[settings.theme];
  
  if (currentScreen == SCREEN_APP_LAUNCHER) {
    drawAppLauncher(t);
    return;
  }
  
  if (currentScreen == SCREEN_MAIN_CLOCK) {
    currentApp = APP_CLOCK;
  }
  
  switch (currentApp) {
    case APP_CLOCK:
      drawClockApp(t);
      break;
    case APP_MESSAGES:
      drawMessagesApp(t);
      break;
    case APP_PHONE:
      drawPhoneApp(t);
      break;
    case APP_MUSIC:
      drawMusicApp(t);
      break;
    case APP_HEALTH:
      drawHealthApp(t);
      break;
    case APP_CAMERA:
      drawCameraApp(t);
      break;
    case APP_SETTINGS:
      drawSettingsApp(t);
      break;
    case APP_CLOCK_TOOLS:
      drawClockToolsApp(t);
      break;
    case APP_COMPASS:
      drawCompassApp(t);
      break;
  }
}

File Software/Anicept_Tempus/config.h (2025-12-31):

#ifndef CONFIG_H
#define CONFIG_H

// Pin definitions
#define BUTTON_1 14
#define BUTTON_2 15
#define BUZZER_PIN 16
#define BATTERY_PIN 4
#define TOUCH_INT 5

// I2S Microphone pins
#define I2S_WS 6
#define I2S_SD 7
#define I2S_SCK 8

// I2C pins
#define I2C_SDA 21
#define I2C_SCL 22

// Display settings
#define SCREEN_WIDTH 240
#define SCREEN_HEIGHT 240
#define CENTER_X 120
#define CENTER_Y 120

// Timing constants
#define SCREEN_TIMEOUT 10000
#define DEBOUNCE_DELAY 50
#define LONG_PRESS_TIME 1000
#define STEP_THRESHOLD 1000
#define STEP_MIN_INTERVAL 300

// BLE UUIDs
#define SERVICE_UUID           "6E400001-B5A3-F393-E0A9-E50E24DCCA9E"
#define CHARACTERISTIC_UUID_RX "6E400002-B5A3-F393-E0A9-E50E24DCCA9E"
#define CHARACTERISTIC_UUID_TX "6E400003-B5A3-F393-E0A9-E50E24DCCA9E"

// Icon sizes
#define ICON_WIDTH 40
#define ICON_HEIGHT 40

#endif

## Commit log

2025-12-31 Add code and update images
    Added Claude AI generated code for Arduino IDE, and updated images to reflect the current PCB
    [Anicept_Tempus.kicad_pcb, Anicept_Tempus.kicad_sch]
2026-03-27 Updated some production files
    [Smartwatch.kicad_pcb, Smartwatch.kicad_sch, bom.csv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]
2026-03-29 Update CAD, PCB, BOM
    [BOM.csv, Back Cover.stl, Bottom Button.stl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]
